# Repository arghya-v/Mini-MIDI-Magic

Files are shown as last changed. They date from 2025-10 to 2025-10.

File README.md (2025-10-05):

# My Custom MIDI Controller 🎛️

**Author:** Arghya Vyas  
**Created On:** September 29, 2025  
**Description:** A simple custom MIDI controller I designed and built from scratch using KiCad and 3D modeling tools.

## 🧠 Overview
This project documents the creation of my custom MIDI controller, from schematic design in KiCad to PCB routing and 3D chassis modeling in TinkerCad.  
I learned about switch matrices, rotary encoders, I2S DAC modules, and custom footprints.

Project journal in the **ORIGINAL-JOURNAL.md** file!

## Rendered Images



## Features

- Compact 4×5 switch matrix for customizable key input

- Rotary encoders for parameter control (e.g. volume, modulation)

- Slide potentiometer for expressive MIDI control

- LCD screen for real-time feedback and menus

- ADS1015 ADC expansion for additional analog inputs

- I2S DAC output for high-quality audio signals

- Custom PCB design built in KiCad

- 3D-printed chassis with modular top and bottom plates

## 🛠️ Tools Used
- **KiCad 9.0** – schematic & PCB design  
- **TinkerCad** – chassis modeling  
- **Hackclub Slack** – troubleshooting and collaboration  
- **Adafruit** – components & footprint references  
- **Orpheus Pico** – main controller  

## 💡 Reflection
This project was a great learning experience — I learned how to:
- Use KiCad effectively for multi-part designs  
- Understand switch matrices and ADC expansion  
- Create and import custom footprints  
- Transition from schematic to PCB  
- Design a printable chassis in CAD  

Overall, this was my first big hardware project, and I’m really proud of how it turned out!

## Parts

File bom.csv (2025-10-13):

Reference | Quantity | Price ($) | Source
Cherry MX Blue Switch | 1 | $2 | https://www.aliexpress.com/item/1005006255961111.html?mp=1
Cherry MX Red Switch | 20 | $13 | https://www.aliexpress.com/item/1005006255961111.html?mp=1
S37735R Screen | 1 | N/A | Included in kit
1N4148 | 22 | N/A | Included in kit
Orpheus Pico | 1 | N/A | Included in kit
PCM 5100 | 1 | N/A | Included in kit
EC11 Rotary Encoders | 2 | N/A | Included in kit
M3 18 mm Screw | 4 | 1.06 | https://us.store.bambulab.com/products/m3-button-head-cap-machine-screws-bhcs?id=42338644951176&skr=yes
M3 4 mm Screw | 4 | 1.06 | https://us.store.bambulab.com/products/m3-button-head-cap-machine-screws-bhcs?id=42338644721800
M2 5 mm Screw | 2 | 1.02 | https://us.store.bambulab.com/products/m2-button-head-cap-machine-screws-bhcs?id=42328200577160
Potentiometer | 1 | 2.95 | https://www.adafruit.com/product/4219
ADS Module (Analog-to-Digital Converter) | 1 | 9.95 | https://www.adafruit.com/product/1083
Total Shipping for BambuLab Parts: $6
Total Shipping for Adafruit Parts: $30 (its alot but I couldnt find a cheaper place)

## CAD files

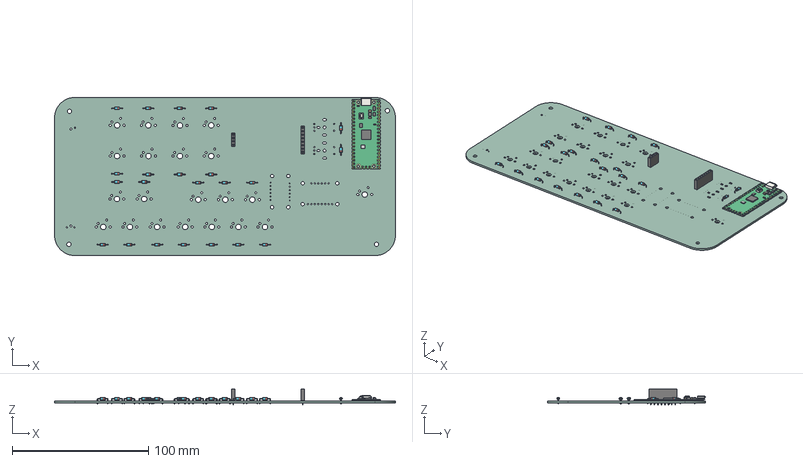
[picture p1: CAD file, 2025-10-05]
CAD-files/MIDI Board-PCB.step
250.0 x 116.0 x 11.6 mm
D_DO-35_SOD27_P7.62mm_Horizontal x 22
PinSocket_1x08_P2.54mm_Vertical
PinSocket_1x04_P2.54mm_Vertical
RaspberryPi_Pico_Module_KiCad
MIDI Board_PCB

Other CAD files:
CAD-files/pcb-with-case.stl

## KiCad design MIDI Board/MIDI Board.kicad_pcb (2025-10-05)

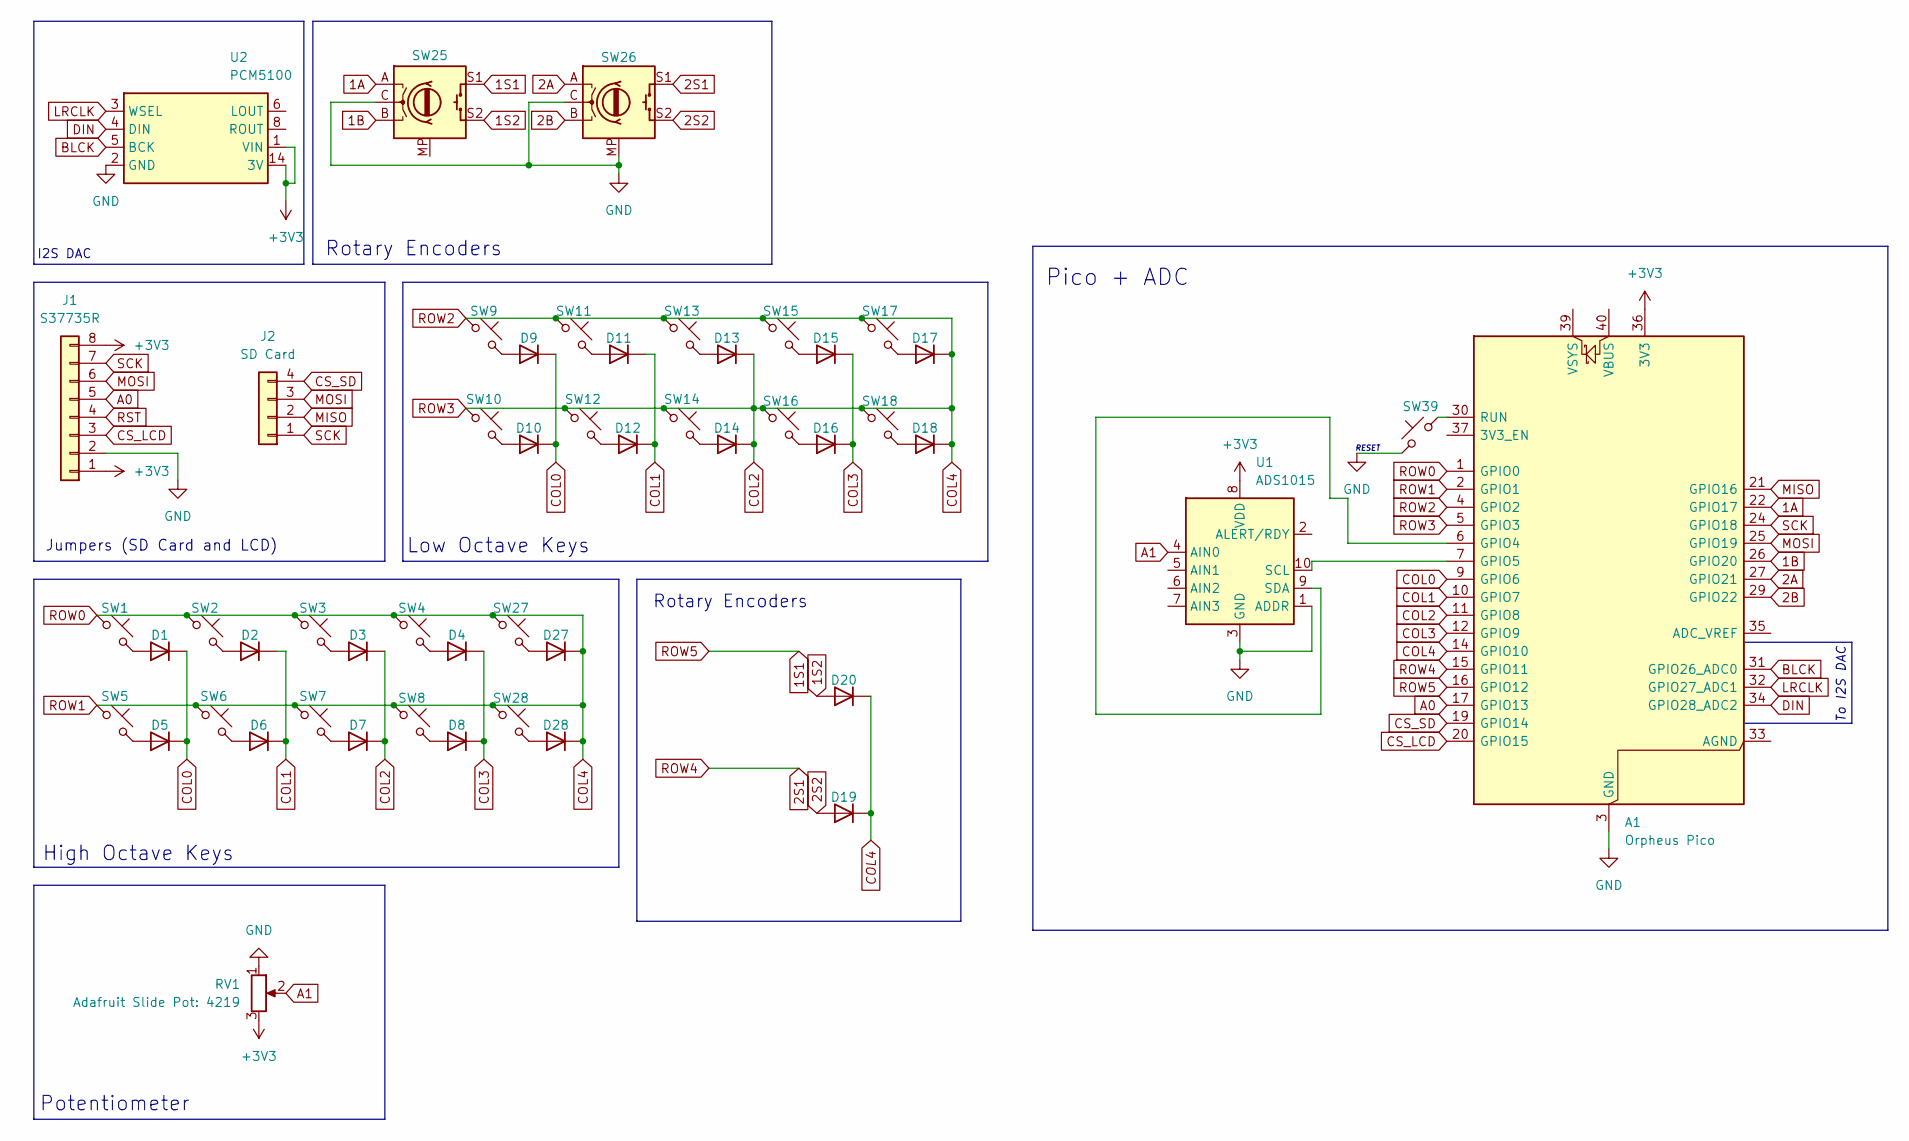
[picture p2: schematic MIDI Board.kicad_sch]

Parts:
A1: Orpheus Pico; RaspberryPi_Pico_Common_Unspecified
D1, D2, D3, D4, D5, D6, D7, D8, D9, D10, D11, D12, D13, D14, D15, D16, D17, D18, D19, D20, D27, D28: 1N4148; D_DO-35_SOD27_P7.62mm_Horizontal
J1: S37735R; PinSocket_1x08_P2.54mm_Vertical
J2: SD Card; PinSocket_1x04_P2.54mm_Vertical
RV1: Adafruit Slide Pot: 4219; Slide_Pot_75mm_Adafruit4219_fixed
SW1, SW2, SW3, SW4, SW6, SW7, SW8, SW9, SW11, SW12, SW13, SW14, SW15, SW16, SW17, SW18, SW27, SW28, SW39: SW_Push_45deg; SW_Cherry_MX_1.00u_PCB
SW5, SW10: SW5; SW_Cherry_MX_1.00u_PCB
SW25, SW26: RotaryEncoder_Switch_MP; RotaryEncoder_Alps_EC11E-Switch_Vertical_H20mm_MountingHoles
U1: ADS1015; Adafruit_ADS1115
U2: PCM5100; PCM5100 I2S DAC

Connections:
1A: A1.22 (GPIO17), SW25.A
1B: A1.26 (GPIO20), SW25.B
1S1: A1.16 (GPIO12), SW25.S1
1S2: D20.2 (A), SW25.S2
2A: A1.27 (GPIO21), SW26.A
2B: A1.29 (GPIO22), SW26.B
2S1: A1.15 (GPIO11), SW26.S1
2S2: D19.2 (A), SW26.S2
+3V3: A1.36 (3V3), J1.1, J1.8, RV1.3, U1.8 (VDD), U2.1 (VIN), U2.14 (3V)
A0: A1.17 (GPIO13), J1.5
A1: RV1.2, U1.4 (AIN0)
BLCK: A1.31 (GPIO26_ADC0), U2.5 (BCK)
COL0: A1.9 (GPIO6), D1.1 (K), D5.1 (K), D9.1 (K), D10.1 (K)
COL1: A1.10 (GPIO7), D2.1 (K), D6.1 (K), D11.1 (K), D12.1 (K)
COL2: A1.1 (GPIO0), A1.2 (GPIO1), A1.4 (GPIO2), A1.5 (GPIO3), A1.11 (GPIO8), A1.14 (GPIO10), D3.1 (K), D7.1 (K), D13.1 (K), D14.1 (K), D17.1 (K), D18.1 (K), D19.1 (K), D20.1 (K), D27.1 (K), D28.1 (K), SW1.1, SW2.1, SW3.1, SW4.1, SW5.1, SW6.1, SW7.1, SW8.1, SW9.1, SW10.1, SW11.1, SW12.1, SW13.1, SW14.1, SW15.1, SW16.1, SW17.1, SW18.1, SW27.1, SW28.1
COL3: A1.12 (GPIO9), D4.1 (K), D8.1 (K), D15.1 (K), D16.1 (K)
CS_LCD: A1.20 (GPIO15), J1.3
CS_SD: A1.19 (GPIO14), J2.4
DIN: A1.34 (GPIO28_ADC2), U2.4 (DIN)
GND: A1.3 (GND), A1.8 (GND), A1.13 (GND), A1.18 (GND), A1.23 (GND), A1.28 (GND), A1.38 (GND), J1.2, RV1.1, SW25.C, SW26.C, SW26.MP, SW39.1, U1.1 (ADDR), U1.3 (GND), U2.2 (GND)
LRCLK: A1.32 (GPIO27_ADC1), U2.3 (WSEL)
MISO: A1.21 (GPIO16), J2.2
MOSI: A1.25 (GPIO19), J1.6, J2.3
unnamed: A1.6 (GPIO4), U1.9 (SDA)
unnamed: A1.7 (GPIO5), U1.10 (SCL)
unnamed: A1.30 (RUN), SW39.2
unnamed: D1.2 (A), SW1.2
unnamed: D2.2 (A), SW2.2
unnamed: D3.2 (A), SW3.2
unnamed: D4.2 (A), SW4.2
unnamed: D5.2 (A), SW5.2
unnamed: D6.2 (A), SW6.2
unnamed: D7.2 (A), SW7.2
unnamed: D8.2 (A), SW8.2
unnamed: D9.2 (A), SW9.2
unnamed: D10.2 (A), SW10.2
unnamed: D11.2 (A), SW11.2
unnamed: D12.2 (A), SW12.2
unnamed: D13.2 (A), SW13.2
unnamed: D14.2 (A), SW14.2
unnamed: D15.2 (A), SW15.2
unnamed: D16.2 (A), SW16.2
unnamed: D17.2 (A), SW17.2
unnamed: D18.2 (A), SW18.2
unnamed: D27.2 (A), SW27.2
unnamed: D28.2 (A), SW28.2
RST: J1.4
SCK: A1.24 (GPIO18), J1.7, J2.1

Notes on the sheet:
I2S DAC
To I2S DAC
Potentiometer
Rotary Encoders
Jumpers (SD Card and LCD)
Low Octave Keys
High Octave Keys
RESET
Pico + ADC

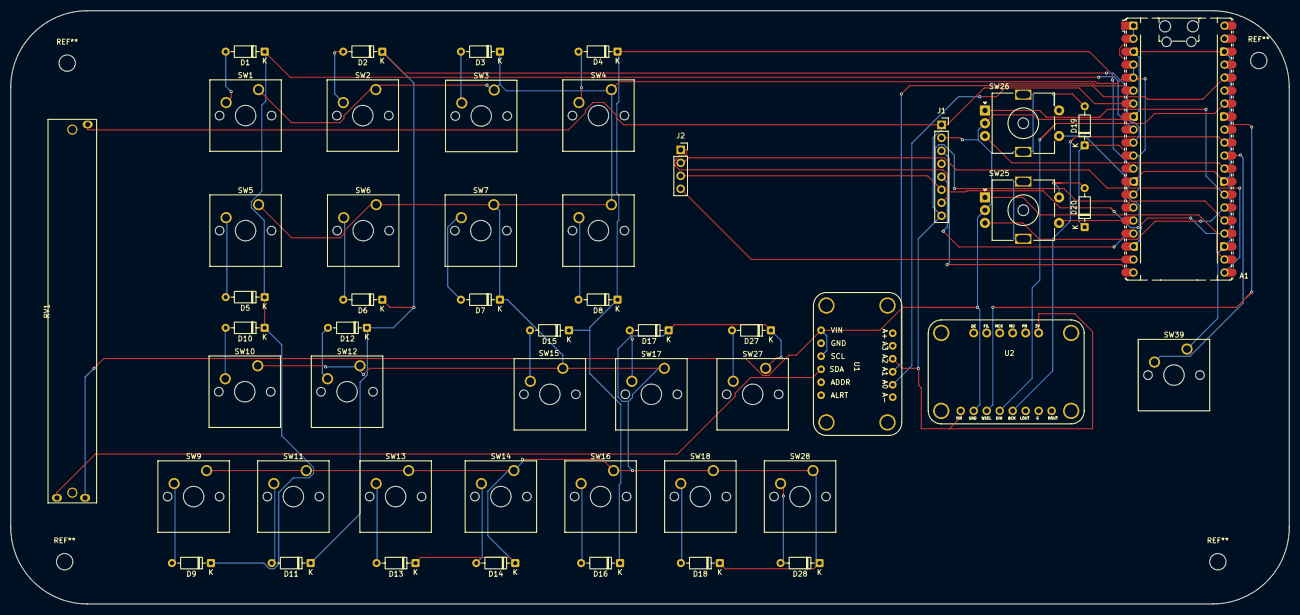
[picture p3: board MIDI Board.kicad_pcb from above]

Board: 2 copper layers, 250.0 x 116.0 mm, 51 parts (0 on the bottom side), 47 nets.

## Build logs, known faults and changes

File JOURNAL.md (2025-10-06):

<!--
  ===================    !!READ THIS NOTICE!!   ====================
  DO NOT edit this file manually. Your changes WILL BE OVERWRITTEN!
  This journal is auto generated and updated by Hack Club Blueprint.
  To edit this file, please edit your journal entries on Blueprint.
  ==================================================================
-->

This is my journal of the design and building process of **Mini MIDI Magic Board**.  
You can view this journal in more detail on **Hack Club Blueprint** [here](https://blueprint.hackclub.com/projects/61).

## 10/3/2025 - Migrating my project!  

I am working on mini midi magic, so now I am migrating my project to blueprint!

Check out the main page here!

https://github.com/arghya-v/Mini-MIDI-Magic/edit/main/JOURNAL.md

Screenshot 2025-10-03 123854.png

So far, I have worked on my schematic, and I am hoping to source my parts from Adafruit  

## 10/6/2025 2:05 PM - Starting (September 24th)  

I started by looking at the mini MIDI magic guide. Alognside that I also installed KiCad and started to learn how it works. I also learned about the switch matrix system, and decided to implement that in my project. Initially, I was confused about the switch matrix and what it meant, but I figured it out and got started by making 4 rows like this



## 10/6/2025 2:06 PM - Rotary Encoders (September 26th)  

After I made my rows, I started to work and learn about rotary encoders, initially, I had made a 6x6 matrix, but I realized that I only need a 4x5 matrix, and I leave the other 2 rows for my rotary encoders. It took me a while to figure it out, because I was new to making schematics, but I luckily got some help on the slack, and then made a schematic like so:





## 10/6/2025 2:15 PM - LCD Screen (September 27th)  

I then proceeded to add on the SD card and LCD screen, I decided to stick with the guide here, because I am new. The LCD was pretty easy to add, but I had to ask some questions regarding the SD card because there wasn't a full screenshot for it. In the end I got it working though.



## 10/6/2025 2:17 PM - Finalizing Schematic (September 29th)  

To finish off, I got my work checked over, fixed an issue with the switches, and then did some organizing. This was my final BASE schematic. I also further organized my my schematic by adding rectangles and text to each component, also crosschecking everything along the way.


I am hoping to add a slide, potentiometer later on and customize it to my liking.  

## 10/6/2025 2:18 PM - Potentiometer (September 29th)  

After some reasearch, I figured out that I needed more ADC pins, so I looked into another breakout board and came across the ADS1015, I then implemented it, and found a footprint online that I could use. After that, I made a simple linear slide potentiometer footprint, and found a 7.5mm one on Adafruit, I then connected it to the ADS breakout board.



## 10/6/2025 2:19 PM - I2S Footprint (September 30th)  

I made the footprint of the I2S DAC module, I efficiently used the .brd file, imported it into kicad, then copied the footprint over.



Later on, I realized that there were a bunch of unnecessary copper pads, so I worked on removing those, and just having the pins  

## 10/6/2025 2:23 PM - Refining I2S Schematic  

I had to refine my schematics and footprints for my I2S DAC, so I updated them and cross checked the correct pins



I removed a lot of the extra pins, and adjusted everything accordingly, the footprint is not perfect, but it covers everything that needs to be used for this project

## 10/6/2025 2:27 PM - Converting to PCB  

I finally converted to a PCB and arranged my parts. I decided to layout my PCB like a midi board, with 8 "pads" on the top, the potentiometer on the side, and piano-like keys near the bottom, with the black keys centered above the white keys. I also added a margin for the screen and arranged my jumpers and powerswitch too. 



## 10/6/2025 2:31 PM - Cadding and PCB  

I routed my PCB using an autorouter to keep the layout simple and efficient. I focused on achieving clean signal paths, minimizing trace crossings, and maintaining a logical component arrangement to ensure reliability and make future debugging or improvements easier.



I also decided to work on my chassis after, to keep it simple, I just used TinkerCad. I added my PCB as a .stl file and started working on the base



## 10/6/2025 2:34 PM - Continuing to CAD (October 3rd)  

I continued to work on some CAD for the chassis, I added internal supports, some keyswitches for reference, and some barriers on the side. I found it easier to CAD with setting my PCB as a hole component so it is transparent, then see through the PCB and place stuff. 





## 10/6/2025 2:35 PM - Finishing Cadding (October 4th)  

I worked on the top plate, kept it at a height of 1.5mm since thats the standard for keyboards, also made holes for the jumpers and encoders



Later on, I finished my overall chassis! Ensured that m3 screws will work, and checked clearances for the components, made the USB hole for the Pico as well. Separated the top and bottom for printing ease



But then I forgot to make a gap for the potentiometer lol, so I just added it



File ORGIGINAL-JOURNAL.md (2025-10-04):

Blueprint bot overwrote my journal, so here it is again

---
Title: "My custom MIDI controller"
Author: "Arghya Vyas"
Description: "A simple MIDI controller I made!"
Created On: "29/9/2025"
---

Note: I kinda forgot I had to journal, but luckily I have screenshots of questions I asked during Slack, so I will use those from the 24th - 29th of September

# September 24th (8PM-10PM)

I started by looking at the mini MIDI magic guide. Alognside that I also installed KiCad and started to learn how it works. I also learned about the switch matrix system, and decided to implement that in my project. 
Initially, I was confused about the switch matrix and what it meant, but I figured it out and got started by making 4 rows like this


<br></br>

# September 26th (7PM - 9PM)

After I made my rows, I started to work and learn about rotary encoders, initially, I had made a 6x6 matrix, but I realized that I only need a 4x5 matrix, and I leave the other 2 rows for my rotary encoders.
It took me a while to figure it out, because I was new to making schematics, but I luckily got some help on the slack, and then made a schematic like so:


<br></br>

# September 27th (10AM - 12 Noon)

I then proceeded to add on the SD card and LCD screen, I decided to stick with the guide here, because I am new. The LCD was pretty easy to add, but I had to ask some questions regarding the SD card because there wasn't a full screenshot for it. In the end I got it working though.


<br></br>

# September 29th (8AM - 9AM)
To finish off, I got my work checked over, fixed an issue with the switches, and then did some organizing. 
This was my final BASE schematic. 

<br></br>
I am hoping to add a slide, potentiometer later on and customize it to my liking.
# September 29th (5PM - 7PM)

After some reasearch, I figured out that I needed more ADC pins, so I looked into another breakout board and came across the ADS1015, I then implemented it, and found a footprint online that I could use.
After that, I made a simple linear slide potentiometer footprint, and found a 7.5mm one on Adafruit, I then connected it to the ADS breakout board. 



# September 30th (5PM - 6PM)

I made the footprint of the I2S DAC module, I efficiently used the .brd file, imported it into kicad, then copied the footprint over. 


<br></br>

# October 1st (5PM - 6:30)

I had to refine my schematics and footprints for my I2S DAC, so I updated them and cross checked the correct pins


<br></br>

# 6:30PM - 8:20 PM
I finally converted to a PCB and arranged my parts


# October 2nd, 5PM-7PM

I routed my PCB, I kept it simple with an autorouter.

<br></br>
I also decided to work on my chassis after, to keep it simple, I just used TinkerCad. I added my PCB as a .stl file and started working on the base

<br></br>

# October 3rd, 5PM-7:50PM

I continued to work on some CAD for the chassis, I added internal supports, some keyswitches for refererence, and some barriers on the side.

<br></br>


<br></br>

# October 4th, 12 noon - 2PM

I worked on the top plate, kept it at a height of 1.5mm since thats the standard for keyboards, also made holes for the jumpers and encoders


<br></br>

# October 4th, 3PM - 4:30PM

I finished my overall chassis! Ensured that m3 screws will work, and checked clearances for the components, made the USB hole for the Pico as well. Separated the top and bottom for printing ease 

<br></br>

# 4:30PM to 4:45PM
Realized I forgot to make a gap for the potentiometer lol, so I just added it

<br></br>

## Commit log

2025-10-05 Rename Dazzling Lappi-Habbi.stl to pcb-with-case.stl
    [Dazzling Lappi-Habbi.stl, pcb-with-case.stl]
2025-10-06 Update and rename MIDI Board-BOM(in) (1).csv to bom.csv
    [bom.csv]
2025-10-13 Update and rename bom - Sheet1.csv to bom.csv
    [bom.csv]
2025-10-13 Update and rename bom - Sheet1 (1).csv to bom.csv
    [bom.csv]
